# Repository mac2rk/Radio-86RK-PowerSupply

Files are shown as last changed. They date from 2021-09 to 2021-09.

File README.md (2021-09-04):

# USB powered Radio-86RK (even from a power bank!)

Compact DC/DC converter to power i8080 and other vintage NMOS ICs from USB.

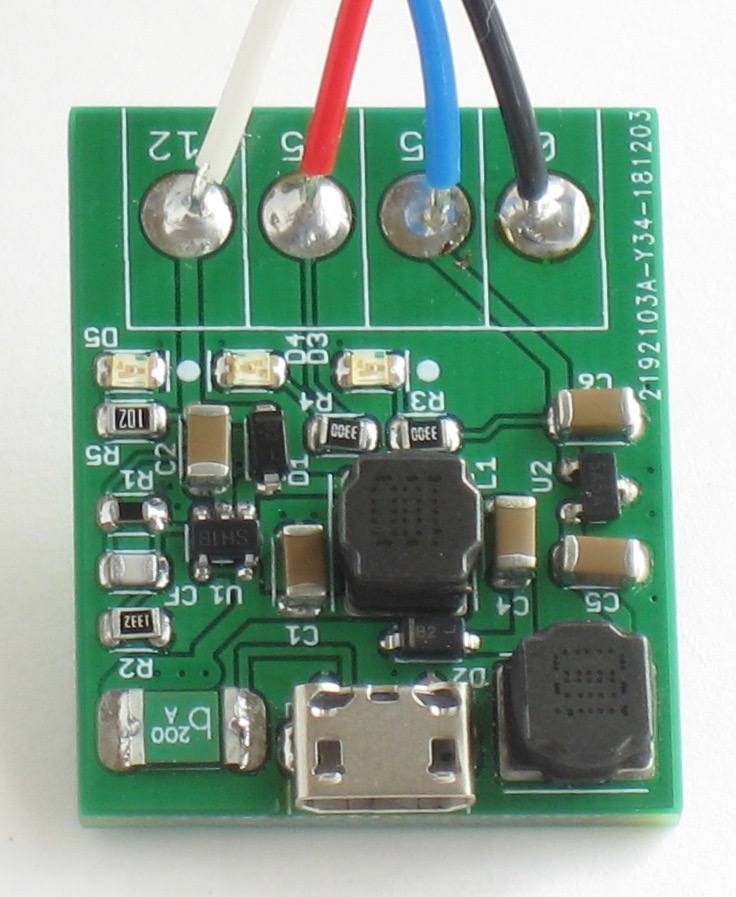
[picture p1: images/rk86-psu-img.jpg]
USB power supply for Radio-86RK


Intel i8080 CPU, MK4116 DRAM, NTE2708 EPROM and similar NMOS ICs from 1970s require three power supply voltages: +12V, -5V and +5V.

This project is a compact DC/DC converter that converts +5V from USB connector to +12V and -5V. This allows powering a retro computer, such as the [Radio-86RK](https://github.com/mac2rk/Radio-86RK-SRAM), from an inexpensive USB wall wart or from a portable battery ("power bank").

Note that some USB wall warts, even rated for high current, drop their output voltage from the nominal 5V to 4.5V and lower when delivering relatively modest 1A. Since +5V is not converted or regulated in any way, using such USB wall wart can affect the performance of the device being powered.

## Schematic and PCB Layout
[Schematic](Eagle/rk86-psu-sch.pdf)

[PCB Layout](Eagle/rk86-psu-pcb.pdf)

## Bill of Materials

Qty | Value   | Device    | Package   | Parts      | Description
--- | ------- | --------- | --------- | ---------- | -----------
1   | LMR62014XMF | IC    | SOT23-5   | U1         | LMR62014 SIMPLE SWITCHER® Step-Up Voltage Regulator 
1   | TC59ECB | IC        | SOT23-3   | U2         | Low Dropout, Negative Output Voltage Regulator                             
2   | MBR0520 | DIODE     | SOD123    | D1, D2     | Schottky diode                                                             
3   |         | LED       | 0805      | D3, D4, D5 |                                                                        
2   | 10u     | Inductor  | SRN6045TA | L1, L2     | Bourns SRN6045TA Series Semi-shielded Power Inductor                                                           
1   | 117k    | Resistor  | 0805      | R1         |
1   | 13.3k   | Resistor  | 0805      | R2         |
2   | 330 ohm | Resistor  | 0805      | R3, R4     |
1   | 1k      | Resistor  | 0805      | R5         |
3   | 2.2uF   | Capacitor | 1206      | C1, C5, C6 | Ceramic capacitor                                                                               
2   | 4.7u    | Capacitor | 1206      | C2, C4     | Ceramic capacitor
1   | 220pF   | Capacitor | 0805      | CF         | Ceramic capacitor                                                                              
1   | 1A      | PTC fuse  | 1812      | F1         |
1   |         | USB connector | Micro USB | USB1   | UJ2-MIBH2-4-SMT

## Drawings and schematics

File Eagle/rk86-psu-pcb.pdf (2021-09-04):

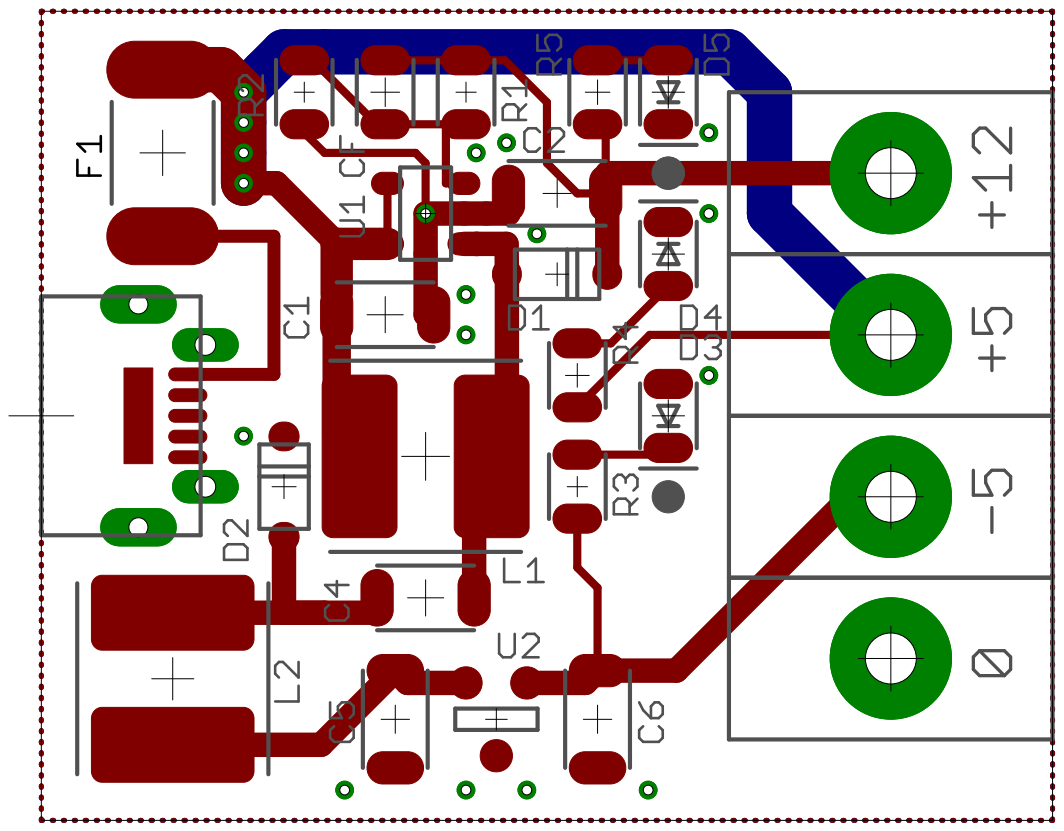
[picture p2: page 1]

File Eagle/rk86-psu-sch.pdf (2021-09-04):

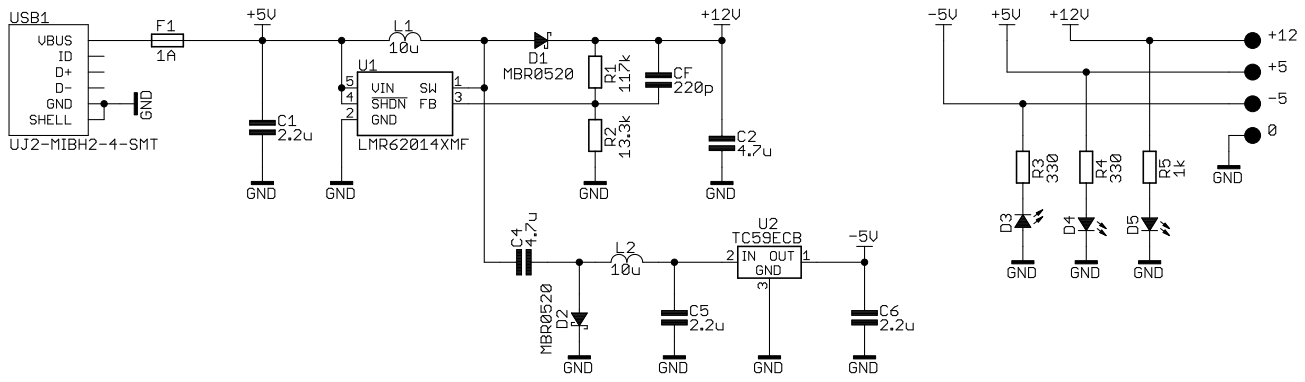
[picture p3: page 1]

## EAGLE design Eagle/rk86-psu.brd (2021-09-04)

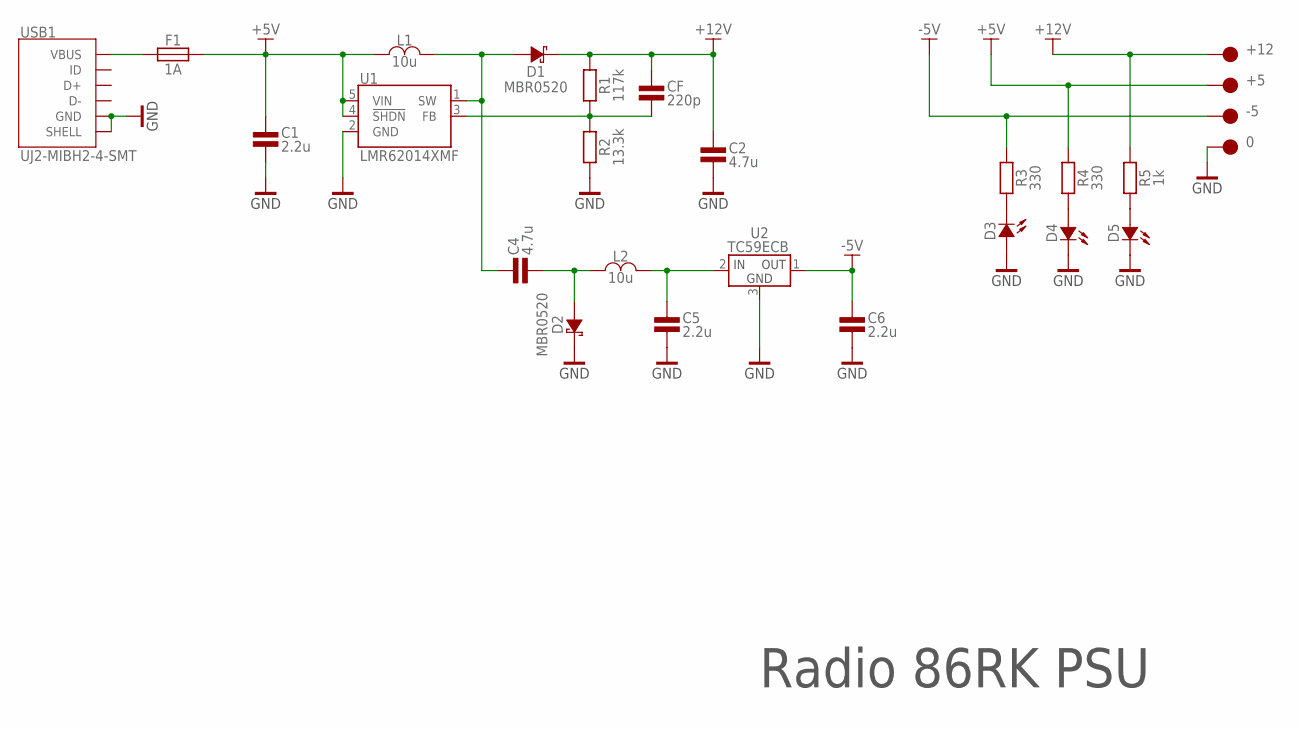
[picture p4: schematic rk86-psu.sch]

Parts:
0: WIREPAD_BOX
+5, +12: WIREPAD_BOX
-5: WIREPAD_BOX
C1, C5, C6: 2.2u; 1206
C2, C4: 4.7u; 1206
CF: 220p; 0805
D1, D2: MBR0520; SOD123
D3, D4, D5: LED0805; 0805POL
F1: 1A; 1812
L1, L2: 10u; BOUNRNS_SRN6045TA
R1: 117k; 0805
R2: 13.3k; 0805
R3, R4: 330; 0805
R5: 1k; 0805
U1: LMR62014XMF; SOT23-5
U2: TC59ECB; SOT23-3
USB1: UJ2-MIBH2-4-SMT

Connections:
+5V: +5.P$1, C1.2, F1.P$2, L1.P$1, R4.2, U1.4 (!SHDN), U1.5 (VIN)
+12V: +12.P$1, C2.2, CF.2, D1.K, R1.2, R5.2
-5V: -5.P$1, C6.2, R3.2, U2.1 (OUT)
GND: 0.P$1, C1.1, C2.1, C5.1, C6.1, D2.K, D3.A, D4.K, D5.K, R2.1, U1.2 (GND), U2.3 (GND), USB1.5 (GND), USB1.S1 (SHELL), USB1.S2 (SHELL), USB1.S3 (SHELL), USB1.S4 (SHELL), USB1.S5 (SHELL)
unnamed: CF.1, R1.1, R2.2, U1.3 (FB)
unnamed: C4.2, D1.A, L1.P$2, U1.1 (SW)
unnamed: C4.1, D2.A, L2.P$1
unnamed: C5.2, L2.P$2, U2.2 (IN)
unnamed: F1.P$1, USB1.1 (VBUS)
unnamed: D3.K, R3.1
unnamed: D4.A, R4.1
unnamed: D5.A, R5.1

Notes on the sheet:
Radio 86RK PSU

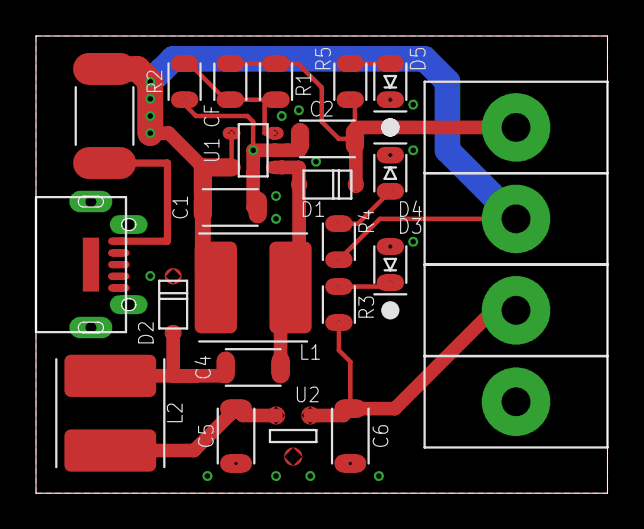
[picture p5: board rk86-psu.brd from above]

Board: 2 copper layers, 31.7 x 25.4 mm, 26 parts (0 on the bottom side), 12 nets.
